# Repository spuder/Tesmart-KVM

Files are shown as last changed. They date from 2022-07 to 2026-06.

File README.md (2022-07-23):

# Testmart-KVM Hacks

 

Tesmart https://www.tesmart.com/collections/dual-monitor/products/4-port-dual-monitor-kvm-switch-hdmi-usb-c-4k60hz-with-usb-hub

This repo contains a collection of code and examples to interface with tesmart devices using a varriety of interfaces

- Serial Port
- Infrared Remote control emulation

## Serial UART control

Buadrate: 9600

| Command | Content | 
| --- | --- |
| AA BB 03 01 01 EE | Switch to PC 1 | 
| AA BB 03 01 02 EE | Switch to PC 2 |
| AA BB 03 01 03 EE | Switch to PC 3 | 
| AA BB 03 01 04 EE | Switch to PC 4 | 
| AA BB 03 02 00 EE | Turn off Buzzer | 
| AA BB 03 02 01 EE | Turn on Buzzer | 
| AA BB 03 03 00 EE | Output A decrease input by 1 | 
| AA BB 03 03 01 EE | Output A increase input by 1 |
| AA BB 03 04 00 EE | Output B decrease input by 1 | 
| AA BB 03 04 01 EE | Output B increase input by 1 |
| AA BB 03 05 01 EE | Switch usb between outputs (in display mode 2) | 
| AA BB 03 06 00 EE | Turn on keyboard mouse passthrough|
| AA BB 03 06 01 EE | Turn off keyboard mouse passthrough|
| AA BB 03 07 01 EE | switch the control hot key to right ctrl|
| AA BB 03 07 00 EE | switch the control hot key to right scrolllock|
| AA BB 03 08 01 EE | turn on auto switching mode|
| AA BB 03 08 00 EE | turn off auto switching mode|
| AA BB 04 09 MM SS EE | Set auto switching time 0x00-0x38, (min 5s)|

Note: I spoke with support and it is not currently possible to emulate the functionality of the Output A and Output B buttons exactly. You can get close by using ` AA BB 03 03 01 EE` and `AA BB 03 04 01 EE` to toggle output A and B between all inputs. 

The tesmart comes with a Pheonix connector. You will need a Serial to pheonix cable



- [Bhphoto pheonix cable](https://www.bhphotovideo.com/c/product/1591175-REG/black_box_avs_cbl_rs232_rs_232_db9_to_phoenix.html)



- [Serial to TTL Adapter](https://www.amazon.com/gp/product/B07BJJ1T5G/ref=ppx_yo_dt_b_search_asin_title?ie=UTF8&psc=1)


- [USB to DB9 Adapter](https://www.amazon.com/gp/product/B00BUZ0K68/ref=ppx_yo_dt_b_search_asin_title?ie=UTF8&psc=1)





### Computer control

You must have an application that can send Serial Communication as "Binary" or "Hex" values. 

Putty is _not_ capable of sending Binary. Instead use [RealTerm](https://sourceforge.net/projects/realterm/) or [USR-TCP Test](https://www.pusr.com/support/downloads/usr-tcp232-test-V13.html)




### Microcontroller control

Arduino Code

```
void setup() {
      Serial.begin(9600);    //TX/RX pins 0/1 on most arduinos
      Serial1.begin(9600);   //TX/RX pins 17/18 on arduino Mega
      const size_t packet_length = 6;
      uint8_t packet[packet_length] = {0xaa, 0xbb, 0x03, 0x01, 0x01, 0xee};
      Serial1.write(packet, packet_length);
}
void loop() {
}
```

See BYO_keyboard_kid/arduino for more examples

Circuit Python

```
uart = busio.UART(board.D1, board.D0, baudrate=9600)
text = bytearray([0xAA, 0xBB, 0x03, 0x01, 0x01, 0xEE])
uart.write(text)
```

See BYO_keyboard_kid/python for more examples





Note many USB keyboards that are based on custom microcontrollers like the [UHK keyboard](https://www.google.com/search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) or BYO Keyboard, are not capable of using the scroll lock + shortcut functionality to switch inputs. Furthermore attempting to use the specialized USB ports will result in media keys (like volume) not working. 

It is recomended to plug keyboards into the non-smart USB ports. 

Additional Information

- https://arduino.stackexchange.com/a/90196/27311
- https://gist.github.com/spuder/628a42e605cd4caa7c4f46dbf7bf47ea
- https://superuser.com/questions/245926/how-does-realterm-send-numbers/1732191#1732191

I am using a 6 key keyboard with a micro controller to send 
- See [BYO_keyboard_kit/README.md](./BYO_keyboard_kit/README.md)

## Infrared



### IR Codes

Codes were captured with a wemos D1 and ESPHome

https://oliverfalvai.com/infrared-smart-remote-esphome/

Remote is `Pronto` format
http://www.remotecentral.com/features/irdisp2.htm

```
# M
# Same as Output A button on device
[12:59:01][D][remote.pronto:229]: Received Pronto: data=0000 006D 0022 0000 015C 00AB 0017 003F 0017 003F 0017 003F 0017 0014 0017 003F 0017 0014 0017 0014 0017 0014 0017 0015 0017 0014 0017 0014 0017 003F 0017 0014 0017 003F 0017 003F 0017 003F 0017 0015 0017 0014 0017 003F 0017 0014 0017 0014 0017 0014 0017 003F 0017 0015 0017 003F 0017 003F 0017 0014 0017 003F 0017 003F 0017 003F 0017 0015 0017 003F 0017 06C3
[12:59:01][D][remote.pronto:229]: Received Pronto: data=0000 006D 0002 0000 015B 0055 0017 06C3
[12:59:01][D][remote.pronto:229]: Received Pronto: data=0000 006D 0002 0000 015C 0056 0017 06C3
```

```
# P
# Same as Output B button on device
[13:01:32][D][remote.pronto:229]: Received Pronto: data=0000 006D 0022 0000 015C 00AC 0015 0041 0016 0041 0017 003F 0016 0016 0017 003F 0016 0016 0016 0015 0016 0016 0015 0016 0016 0015 0016 0016 0016 0041 0017 0014 0016 0040 0016 0041 0016 0040 0016 0041 0016 0040 0016 0040 0016 0016 0016 0016 0016 0015 0016 0040 0016 0015 0016 0016 0016 0015 0016 0015 0016 0040 0016 0040 0016 0040 0016 0015 0016 0040 0016 06C3
[13:01:32][D][remote.pronto:229]: Received Pronto: data=0000 006D 0002 0000 015C 0056 0016 06C3

```

```
# 1
# Same as button 1 on device
[12:59:01][D][remote.pronto:229]: Received Pronto: data=0000 006D 0022 0000 015C 00AB 0017 003F 0017 003F 0017 003F 0017 0014 0017 003F 0017 0014 0017 0014 0017 0014 0017 0015 0017 0014 0017 0014 0017 003F 0017 0014 0017 003F 0017 003F 0017 003F 0017 0015 0017 0014 0017 003F 0017 0014 0017 0014 0017 0014 0017 003F 0017 0015 0017 003F 0017 003F 0017 0014 0017 003F 0017 003F 0017 003F 0017 0015 0017 003F 0017 06C3
[12:59:01][D][remote.pronto:229]: Received Pronto: data=0000 006D 0002 0000 015B 0055 0017 06C3
[12:59:01][D][remote.pronto:229]: Received Pronto: data=0000 006D 0002 0000 015C 0056 0017 06C3
```
```
# 2
# Same as button 2 on device
[12:59:41][D][remote.pronto:229]: Received Pronto: data=0000 006D 0022 0000 015B 00AC 0016 0040 0016 0040 0016 0040 0016 0016 0016 0040 0016 0016 0016 0016 0016 0016 0016 0015 0016 0016 0016 0016 0016 0040 0016 0015 0016 0040 0016 0040 0016 0040 0016 0040 0016 0040 0016 0016 0016 0016 0016 0016 0016 0016 0016 0040 0016 0015 0016 0015 0016 0015 0016 0040 0016 0040 0016 0040 0016 0040 0016 0016 0015 0040 0016 06C3
[12:59:41][D][remote.pronto:229]: Received Pronto: data=0000 006D 0002 0000 015B 0055 0016 06C3

```
```
# 3
# Same as button 3 on device
[12:59:41][D][remote.pronto:229]: Received Pronto: data=0000 006D 0002 0000 015B 0055 0016 06C3
[13:00:06][D][remote.pronto:229]: Received Pronto: data=0000 006D 0022 0000 015C 00AB 0017 003F 0017 003F 0017 003F 0017 0014 0017 003F 0017 0014 0017 0014 0017 0014 0017 0014 0017 0014 0017 0014 0017 003F 0017 0014 0017 003F 0017 003F 0017 003F 0017 003F 0017 003F 0017 003F 0017 0014 0017 0015 0017 0014 0017 0014 0017 0014 0017 0014 0017 0014 0017 0014 0017 003F 0017 003F 0017 003F 0017 003F 0017 003F 0017 06C3
[13:00:13][D][remote.pronto:229]: Received Pronto: data=0000 006D 0002 0000 0079 0004 0008 06C3

```

```
# 4
# Same as button 4 on device
[13:00:43][D][remote.pronto:229]: Received Pronto: data=0000 006D 0022 0000 015B 00AB 0017 003F 0016 0040 0017 003F 0016 0017 0015 003F 0017 0015 0016 0015 0017 0015 0016 0016 0017 0015 0017 0015 0016 0040 0017 0015 0017 003F 0017 003F 0017 003F 0017 003F 0016 0015 0017 0015 0017 003F 0017 0015 0017 0015 0016 0015 0017 0015 0017 0015 0017 003F 0017 003F 0017 0015 0017 003F 0017 003F 0017 003F 0017 003F 0017 06C3
[13:00:44][D][remote.pronto:229]: Received Pronto: data=0000 006D 0002 0000 015C 0055 0017 06C3

```

```
# 5
# Same as button 5 on device
[13:01:00][D][remote.pronto:229]: Received Pronto: data=0000 006D 0022 0000 015C 00AB 0017 003F 0017 003F 0017 003F 0017 0015 0017 003F 0016 0016 0016 0016 0016 0016 0017 0015 0016 0015 0017 0015 0017 003F 0016 0016 0017 003F 0017 003F 0016 0040 0016 0015 0017 003F 0017 003F 0017 0014 0017 003F 0017 0015 0017 0014 0017 0015 0017 003F 0017 0014 0017 0014 0017 003F 0017 0014 0017 003F 0017 003F 0017 003F 0017 06C3
[13:01:00][D][remote.pronto:229]: Received Pronto: data=0000 006D 0002 0000 015C 0055 0016 06C3

```

```
# Circle
# Same as Circle 
[13:01:55][D][remote.pronto:229]: Received Pronto: data=0000 006D 0022 0000 015C 00AC 0016 0040 0017 003F 0017 003F 0017 0015 0017 003F 0016 0016 0017 0016 0015 0015 0017 0016 0015 0015 0017 0015 0017 003F 0016 0015 0017 003F 0017 003F 0017 003F 0016 0040 0017 0015 0016 0040 0017 003F 0017 0015 0017 0014 0017 0015 0017 0014 0017 0014 0017 003F 0017 0015 0017 0015 0017 003F 0017 003F 0017 0040 0016 0040 0017 06C3
[13:01:55][D][remote.pronto:229]: Received Pronto: data=0000 006D 0002 0000 015C 0055 0016 06C3

```

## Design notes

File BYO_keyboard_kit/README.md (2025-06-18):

# BYO_keyboard_kit

The BYO keyboard was a [succesfull kickstarter](https://www.kickstarter.com/projects/painlessprototyping/byo-build-your-own-mechanical-keyboard) for a 6 key or 9 key keyboard

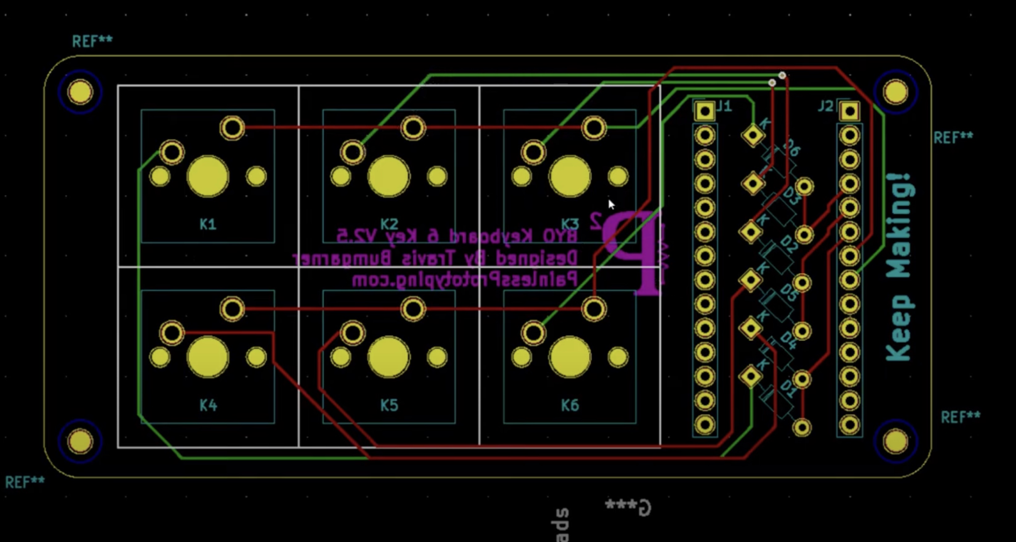
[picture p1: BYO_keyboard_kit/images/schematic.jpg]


Github: https://github.com/painlessprototyping/byo_keyboard_code

**Microprocessor: ItsyBitsy M0 Express**



ItsyBitsy M0 Express Additional Information
- https://learn.adafruit.com/introducing-itsy-bitsy-m0
- https://github.com/adafruit/Adafruit-ItsyBitsy-M0-PCB
  
## Modifications

Solder 2 wires to pins 0 and 1 on the microcontroller. (TX/RX). 

Wire up those pins as shown below. 

For debugging on a computer, wire up to a USB to TTL logic converter like the USB Bub. Use RealTerm(windows) or CoolTerm(mac) to view the output of the serial port

For connecting to a tesmart, use a RS232 to TTL adapter

- [RS232-TTL (Amazon)](https://www.amazon.com/dp/B07BJJ1T5G?psc=1&ref=ppx_yo2ov_dt_b_product_details)

It can be programed with either arduino or micropython

## Circuit Python

Install circuit python from here: https://circuitpython.org/board/itsybitsy_m0_express/ and [here](https://learn.adafruit.com/introducing-itsy-bitsy-m0/circuitpython)

Download the library bundle from [here](https://circuitpython.org/libraries)

Once circuit python is running on the board, a new flash device will appear on your desktop. 

1. Copy `adafruit_hid/`, `adafruit_dotstar.mpy` and `adafruit_matrixkeypad.mpy` from the downloaded circuitpython zip to the `lib` folder on the device
2. Edit `code.py` on the flash device

The code will load instantly and automatically reboot the micro controller

If you get stuck, See [these instructions](https://github.com/painlessprototyping/byo_keyboard_code/tree/master/byo_sample_code/circuit_python). Note that they reference an older version of cirucit python. 

## Arduino

Install the M0 support in arduino ide

https://learn.adafruit.com/introducing-itsy-bitsy-m0/setup

https://www.adafruit.com/product/3727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

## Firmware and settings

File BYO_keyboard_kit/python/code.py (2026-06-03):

import time
import board
import digitalio
import adafruit_matrixkeypad
import busio
import adafruit_dotstar as dotstar

# Initial delay for stable startup
time.sleep(1)

# Hardware initialization
cols = [digitalio.DigitalInOut(x) for x in (board.D11, board.D12, board.D13)]
rows = [digitalio.DigitalInOut(x) for x in (board.D9, board.D10)]
keys = ((0, 1, 2), (3, 4, 5))

keypad = adafruit_matrixkeypad.Matrix_Keypad(rows, cols, keys)
uart = busio.UART(board.D1, board.D0, baudrate=9600)
dots = dotstar.DotStar(board.APA102_SCK, board.APA102_MOSI, 1, brightness=0.1)

# Color definitions - optimized values
COLORS = [
    (100, 0, 0),    # red - display 0
    (255, 165, 0),  # orange - display 1
    (0, 255, 0),    # green - display 2
    (128, 0, 128),  # purple - display 3
]

# UART command templates
UART_COMMANDS = {
    0: bytearray([0xAA, 0xBB, 0x03, 0x01, 0x01, 0xEE]),  # Set display 0
    1: bytearray([0xAA, 0xBB, 0x03, 0x01, 0x02, 0xEE]),  # Set display 1
    2: bytearray([0xAA, 0xBB, 0x03, 0x01, 0x03, 0xEE]),  # Set display 2
    3: bytearray([0xAA, 0xBB, 0x03, 0x03, 0x01, 0xEE]),  # Cycle primary
    4: bytearray([0xAA, 0xBB, 0x03, 0x04, 0x01, 0xEE]),  # Cycle secondary
    5: bytearray([0xAA, 0xBB, 0x03, 0x05, 0x01, 0xEE]),  # Swap displays
}

# State variables
primary_display = 0
secondary_display = 1

# Initialize LED color
dots[0] = COLORS[primary_display]

def send_uart_message(command_key):
    """Send UART message with error handling"""
    try:
        uart.write(UART_COMMANDS[command_key])
    except Exception as e:
        print(f"UART Error: {e}")

def update_led_color():
    """Update DotStar LED color based on primary display"""
    dots[0] = COLORS[primary_display]

# Main loop
last_pressed_keys = []
last_key_time = 0
DEBOUNCE_TIME = 0.15

while True:
    pressed_keys = keypad.pressed_keys
    now = time.monotonic()

    # Only act on newly pressed keys (not keys held from previous loop)
    new_keys = [k for k in pressed_keys if k not in last_pressed_keys]

    if new_keys and (now - last_key_time) > DEBOUNCE_TIME:
        key = new_keys[0]
        last_key_time = now

        if key <= 2:  # Keys 0, 1, 2: Set both displays to same value
            primary_display = key
            secondary_display = key
            update_led_color()
            send_uart_message(key)

        elif key == 3:  # Cycle primary display
            primary_display = (primary_display + 1) % 4
            update_led_color()
            send_uart_message(3)

        elif key == 4:  # Cycle secondary display
            secondary_display = (secondary_display + 1) % 4
            send_uart_message(4)

        elif key == 5:  # Swap displays
            primary_display, secondary_display = secondary_display, primary_display
            update_led_color()
            send_uart_message(5)

    last_pressed_keys = pressed_keys

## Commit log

2022-07-30 add schematic
    [Schematic.fzz]
2024-07-09 update circuit python
2026-10-16 Use built-in keypad.KeyMatrix for debounced key events
    Replace the hand-rolled edge detection and global time debounce over
    adafruit_matrixkeypad with CircuitPython's keypad.KeyMatrix event queue.
    This fixes double actions from release bounce, keys dropped when pressed
    inside the debounce window, and reliance on low-precision monotonic().
    Also sleep when idle, hoist the shared LED/UART calls, and drop
    adafruit_matrixkeypad from the README install steps.
2026-10-16 Document KVM serial output and sync keypad LED from it
    The KVM sends undocumented ASCII status lines ("Set ch is N",
    "Querry pc LED", "Write EEPROM") on its TX line when the input changes.
    Document them with hex in the README, and have code.py parse
    "Set ch is N" to keep the DotStar in sync with the KVM.
    Switch back to adafruit_matrixkeypad: the SAMD21 CircuitPython build
    has no keypad module, so the KeyMatrix version crashed on the board.
2026-10-16 Track outputs A and B separately; note echo counts and missing query
    Output A/B presses send a single "Set ch is N" that doesn't say which
    output moved. Since those buttons step to the next PC, infer the output
    from the current state, guessing A when both outputs are on the same PC.
    Print both outputs' state to the console; the DotStar still shows A.
    README: document that serial, front-panel 1-4 and Output A/B triggers
    echo 3, 2 and 1 lines, and that this model doesn't answer the
    AA BB 03 10 00 EE query some Tesmart switches support.
2026-10-16 Widen KVM echo burst window to 250 ms
    A serial switch's three-line echo arrived as one line, then two more
    after a gap longer than 100 ms, so the parser split one burst in two.
